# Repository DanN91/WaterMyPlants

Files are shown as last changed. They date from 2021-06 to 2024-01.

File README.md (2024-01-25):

# WaterMyPlants

#### Software and Hardware ( ATMega328P ) system aimed to keep our plants alive for a reasonable amount of time while we enjoy our vacation.

Functionalities ( Strategies, changeable at run-time ):
1. **Manual** mode: turn the water pump on/off via a button push;
2. **Timer** mode: turn the water pump on/off for a specific duration of time and with a specific frequency ( once every x days );
3. **Sensor** mode: monitor the soil moisture and calibrate wetness and dryness levels, then water the plants whenever set dryness level is reached, up to the set wetness level.

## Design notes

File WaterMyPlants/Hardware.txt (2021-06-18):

*** Water My Plants Hardware Components ***

*** Components ***
3 x Momentary Switch
3 x 10k Resistor

1 x 10mm LED
1 x 10k Resistor

1 x Photoresistor
1 x 10k Resistor

1 x 2N2222 Transistor
1 x 1k Resistor

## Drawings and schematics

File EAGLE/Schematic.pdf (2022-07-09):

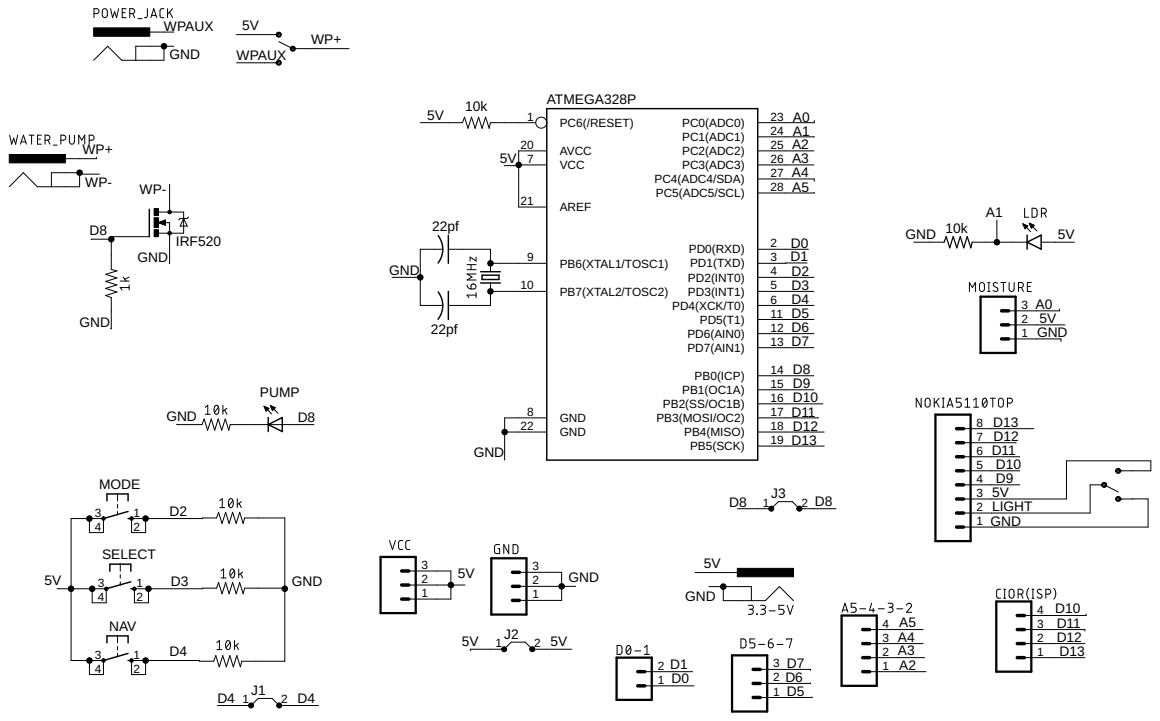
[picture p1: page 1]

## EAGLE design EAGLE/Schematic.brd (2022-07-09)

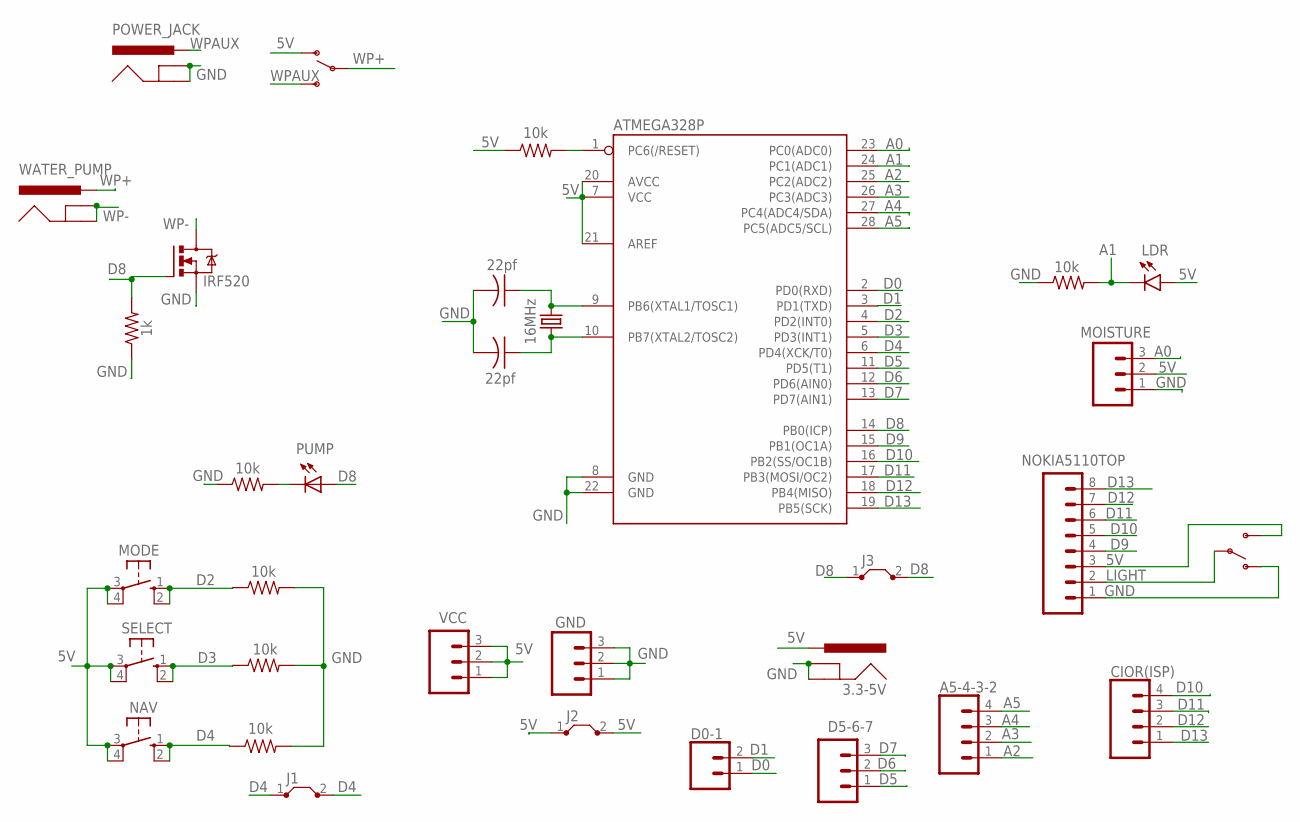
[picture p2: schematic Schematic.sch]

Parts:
3.3-5V: POWER_JACK; POWER_JACK_PTH
5V/AUX: SWITCH-SPDT-PTH-11.6X4.0MM-LOCK; SWITCH_SPDT_PTH_11.6X4.0MM_LOCK
A5-4-3-2: CONN_04; 1X04
ATMEGA328P: 328P; DIP28
AUX_POWER: POWER_JACK; POWER_JACK_PTH
C1, C2: 22pf; C025-024X044
CIOR(ISP): CONN_04; 1X04
D0-1: CONN_02; 1X02
D5-6-7: CONN_03; 1X03
GND: CONN_03; 1X03
GND/VCC: SWITCH-SPDT-PTH-11.6X4.0MM-LOCK; SWITCH_SPDT_PTH_11.6X4.0MM_LOCK
J1, J2, J3: J5MM; 05
LDR: LED3MM; LED_3MM
MODE: 10-XX; B3F-10XX
MOISTURE: CONN_03; 1X03
NAV: 10-XX; B3F-10XX
NOKIA5110TOP: CONN_08"; 1X08
PUMP: LED5MM
Q1: IRF520; TO220BV
R2, R3, R4, R5, R7: 10k; AXIAL-0.1
R6: 10k; 0207/2V
R8: 1k; AXIAL-0.1
SELECT: 10-XX; B3F-10XX
VCC: CONN_03; 1X03
WATER_PUMP: WATER_PUMP; POWER_JACK_PTH
Y1: 16MHz; HC49US

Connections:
5V: 3.3-5V.PWR, 5V/AUX.1 (O), ATMEGA328P.7 (VCC), ATMEGA328P.20 (AVCC), ATMEGA328P.21 (AREF), GND/VCC.3 (S), J2.1, J2.2, LDR.A, MODE.3, MODE.4 (P1), MOISTURE.2, NAV.3, NAV.4 (P1), NOKIA5110TOP.3, R7.P$1 (1), SELECT.3, SELECT.4 (P1), VCC.1, VCC.2, VCC.3
A0: ATMEGA328P.23 (PC0(ADC0)), MOISTURE.3
A1: ATMEGA328P.24 (PC1(ADC1)), LDR.K (C), R6.2
A2: A5-4-3-2.1, ATMEGA328P.25 (PC2(ADC2))
A3: A5-4-3-2.2, ATMEGA328P.26 (PC3(ADC3))
A4: A5-4-3-2.3, ATMEGA328P.27 (PC4(ADC4/SDA))
A5: A5-4-3-2.4, ATMEGA328P.28 (PC5(ADC5/SCL))
D0: ATMEGA328P.2 (PD0(RXD)), D0-1.1
D1: ATMEGA328P.3 (PD1(TXD)), D0-1.2
D2: ATMEGA328P.4 (PD2(INT0)), MODE.1 (S), MODE.2 (S1), R5.P$1 (1)
D3: ATMEGA328P.5 (PD3(INT1)), R4.P$1 (1), SELECT.1 (S), SELECT.2 (S1)
D4: ATMEGA328P.6 (PD4(XCK/T0)), J1.1, J1.2, NAV.1 (S), NAV.2 (S1), R3.P$1 (1)
D5: ATMEGA328P.11 (PD5(T1)), D5-6-7.1
D6: ATMEGA328P.12 (PD6(AIN0)), D5-6-7.2
D7: ATMEGA328P.13 (PD7(AIN1)), D5-6-7.3
D8: ATMEGA328P.14 (PB0(ICP)), J3.1, J3.2, PUMP.A, Q1.G, R8.P$2 (2)
D9: ATMEGA328P.15 (PB1(OC1A)), NOKIA5110TOP.4
D10: ATMEGA328P.16 (PB2(SS/OC1B)), CIOR(ISP).4, NOKIA5110TOP.5
D11: ATMEGA328P.17 (PB3(MOSI/OC2)), CIOR(ISP).3, NOKIA5110TOP.6
D12: ATMEGA328P.18 (PB4(MISO)), CIOR(ISP).2, NOKIA5110TOP.7
D13: ATMEGA328P.19 (PB5(SCK)), CIOR(ISP).1, NOKIA5110TOP.8
GND: 3.3-5V.GND, 3.3-5V.GNDBREAK, ATMEGA328P.8 (GND), ATMEGA328P.22 (GND), AUX_POWER.GND, AUX_POWER.GNDBREAK, C1.2, C2.2, GND.1, GND.2, GND.3, GND/VCC.1 (O), MOISTURE.1, NOKIA5110TOP.1, Q1.S, R2.P$1 (1), R3.P$2 (2), R4.P$2 (2), R5.P$2 (2), R6.1, R8.P$1 (1)
LIGHT: GND/VCC.2, NOKIA5110TOP.2
unnamed: PUMP.K (C), R2.P$2 (2)
unnamed: ATMEGA328P.9 (PB6(XTAL1/TOSC1)), C1.1, Y1.2
unnamed: ATMEGA328P.10 (PB7(XTAL2/TOSC2)), C2.1, Y1.1
unnamed: ATMEGA328P.1 (PC6(/RESET)), R7.P$2 (2)
WP+: 5V/AUX.2, WATER_PUMP.PWR
WP-: Q1.D, WATER_PUMP.GND, WATER_PUMP.GNDBREAK
WPAUX: 5V/AUX.3 (S), AUX_POWER.PWR

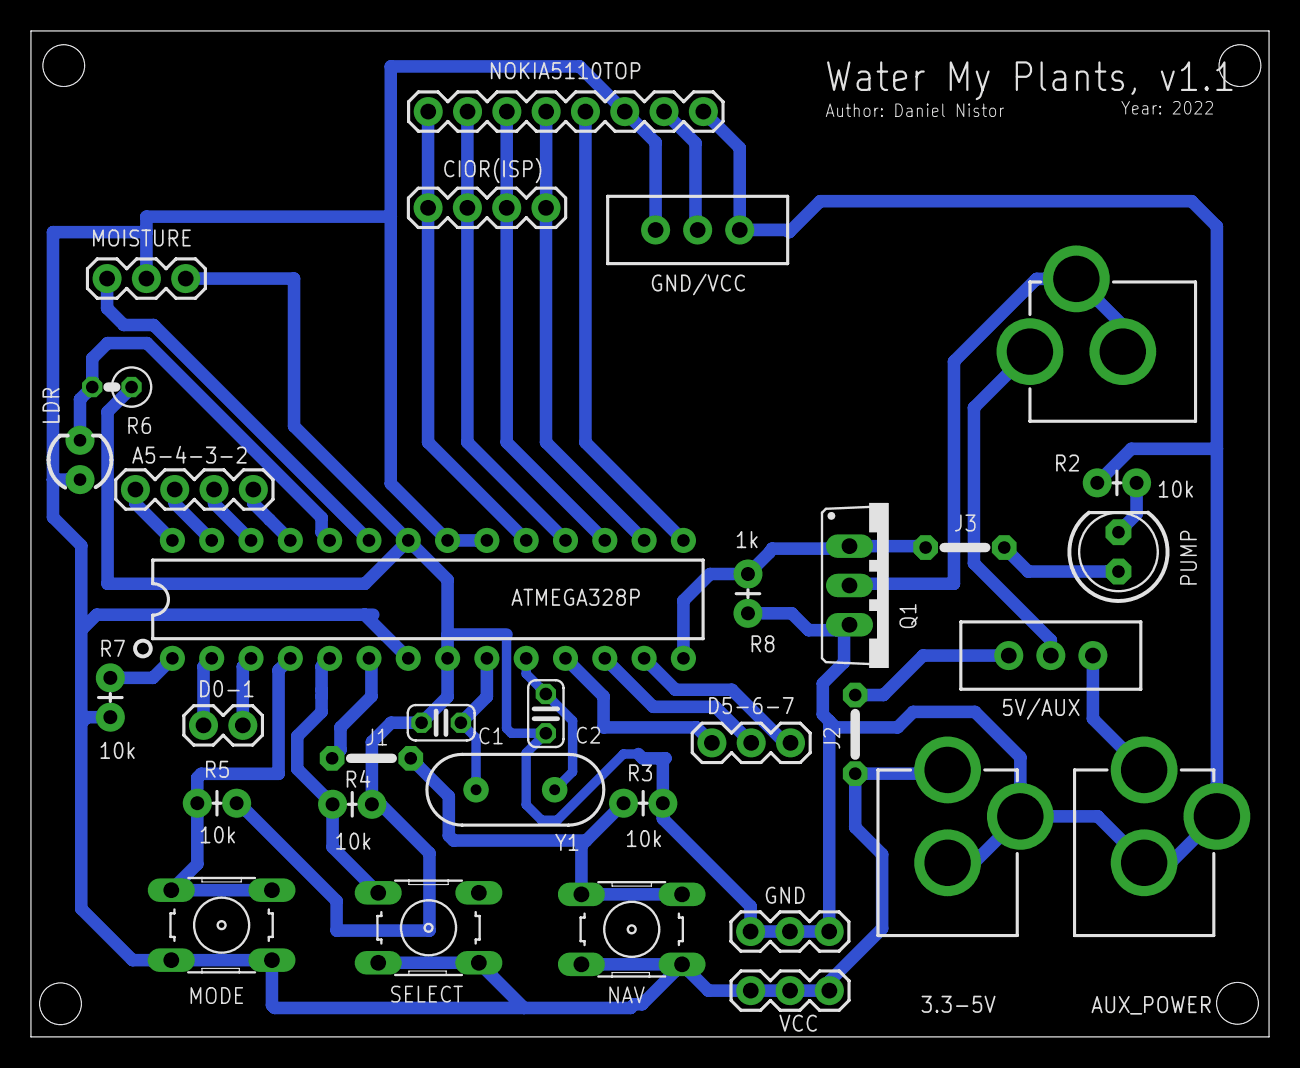
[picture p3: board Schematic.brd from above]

Board: 2 copper layers, 80.0 x 65.0 mm, 33 parts (0 on the bottom side), 30 nets.

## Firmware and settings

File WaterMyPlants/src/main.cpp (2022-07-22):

#include <Arduino.h>

#include <Hardware.h>
#include <PushButton.h>
#include <NokiaDisplay.h>
#include <MenuCursor.h>
#include <MenuCreator.h>
#include <MenuController.h>
#include <SettingsManager.h>
#include <StringsManager.h>
#include <TimerManager.h>

#include <SoilMoistureSensor.h>
#include <LightSensor.h>

#include <OperationModeHandler.h>
#include <RangeValuesGenerator.h>
#include <ChangeSetting.h>

#include <ManualMode.h>
#include <TimerMode.h>
#include <SensorMode.h>

#include <Menu.h>

PushButton modeChangerButton(Hardware::MODE_CHANGER_BUTTON_PIN);
PushButton executionButton(Hardware::EXECUTION_BUTTON_PIN);
OperationModeHandler operationHandler(modeChangerButton);

NokiaDisplay display(Hardware::NOKIA_RESET_PIN,
    Hardware::NOKIA_CHIP_ENABLE_PIN,
    Hardware::NOKIA_DATA_SELECT_PIN,
    Hardware::NOKIA_DATA_IN_PIN,
    Hardware::NOKIA_CLOCK_PIN);
PushButton menuNavigationButton(Hardware::MENU_NAVIGATION_BUTTON_PIN);
MenuController menuController(display, modeChangerButton, menuNavigationButton, executionButton, operationHandler);

// Operation Modes
WaterPump waterPump(Hardware::WATER_PUMP_PIN);
ManualMode manualMode(waterPump, executionButton);

TimerManager timerManager(1); // Observers: [TimerMode]
TimerMode timerMode(waterPump, timerManager);

SoilMoistureSensor soilMoistureSensor(Hardware::SOIL_MOISTURE_SENSOR_PIN, SoilMoistureSensor::Sensitivity::Medium);
LightSensor lightSensor(Hardware::LIGHT_SENSOR_PIN, LightSensor::Sensitivity::High);
SensorMode sensorMode(soilMoistureSensor, lightSensor, waterPump);

void setup()
{
    // Serial.begin(115200); // #TODO:TESTONLY
    timerManager.Initialize();
    timerManager.Activate();

    // Operation Mode Handler
    operationHandler.Add(manualMode);
    operationHandler.Add(timerMode);
    operationHandler.Add(sensorMode);

    operationHandler.Initialize();

    // initialize hardware components
    modeChangerButton.Initialize();
    menuNavigationButton.Initialize();
    executionButton.Initialize();
    waterPump.Initialize();

    // call once, then comment and recompile + upload
    // StringsManager stringsManager(Language::English);
    // stringsManager.WriteAllStrings();
    // SettingsManager::WriteDefaultSettings();

    display.Initialize();
    menuController.Initialize();
}

uint32_t previous = millis();

// CALIBRATION ONLY
uint16_t minMoisture = 1000;
uint16_t maxMoisture = 0;

uint16_t minLight = 1000;
uint16_t maxLight = 0;

void loop()
{
    // buttons
    modeChangerButton.HandleEvents();
    menuNavigationButton.HandleEvents();
    executionButton.HandleEvents();
    lightSensor.HandleEvents();
    soilMoistureSensor.HandleEvents();

    operationHandler.Run();
    menuController.Handle();

    // on Manual menu show this data for calibration purposes
    if (menuController.IsEmptyMenu() && (millis() - previous) >= 1500) // once every second
    {
        // const auto PrintSensorValues = [](const char* name, uint16_t rawValue, uint8_t percentValue){
        //     Serial.print(name);
        //     Serial.print(rawValue);
        //     Serial.print(" ( ");
        //     Serial.print(percentValue);
        //     Serial.println(" % )");
        // };

        const auto lightValue = lightSensor.RawValue();
        // const auto lightPercent = lightSensor.Value();
        // PrintSensorValues("Light: ", lightValue, lightPercent);

        const auto moistureValue = soilMoistureSensor.RawValue();
        // const auto moisturePercent = soilMoistureSensor.Value();
        // PrintSensorValues("Moisture: ", moistureValue, moisturePercent);

        display.SetCursor(4, 0);
        display.ClearLine();

        String currentLight("L: ");
        currentLight.concat(lightValue);
        currentLight.concat("/");
        currentLight.concat(lightSensor.Value());
        currentLight.concat(" %");

        display.Write(currentLight);

        display.SetCursor(5, 0);
        display.ClearLine();

        String currentMoisture("M: ");
        currentMoisture.concat(moistureValue);
        currentMoisture.concat("/");
        currentMoisture.concat(soilMoistureSensor.Value());
        currentMoisture.concat(" %");

        display.Write(currentMoisture);

        // Update and show Min and Max
        if (moistureValue < minMoisture)
            minMoisture = moistureValue;

        if (moistureValue > maxMoisture)
            maxMoisture = moistureValue;

        if (lightValue < minLight)
            minLight = lightValue;

        if (lightValue > maxLight)
            maxLight = lightValue;

        String lightStats("L: ");
        lightStats.concat(minLight);
        lightStats.concat("/");
        lightStats.concat(maxLight);

        display.SetCursor(2, 0);
        display.ClearLine();
        display.Write(lightStats);

        String moistureStats("M: ");
        moistureStats.concat(minMoisture);
        moistureStats.concat("/");
        moistureStats.concat(maxMoisture);

        display.SetCursor(3, 0);
        display.ClearLine();
        display.Write(moistureStats);

        previous = millis();
    }
}

// ISR used by timer manager to notify observers
ISR(TIMER1_COMPA_vect)
{
    timerManager.OnTrigger();
}

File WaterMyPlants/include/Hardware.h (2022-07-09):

/*
    ...
*/

#pragma once

#include <Arduino.h>

namespace Hardware
{
    constexpr uint8_t SOIL_MOISTURE_SENSOR_PIN = A0;
    constexpr uint8_t LIGHT_SENSOR_PIN = A1;

    constexpr uint8_t WATER_PUMP_PIN = 8;
    constexpr uint8_t MODE_CHANGER_BUTTON_PIN = 2;
    constexpr uint8_t EXECUTION_BUTTON_PIN = 3;
    constexpr uint8_t MENU_NAVIGATION_BUTTON_PIN = 4;

    constexpr uint8_t NOKIA_RESET_PIN = 13;
    constexpr uint8_t NOKIA_CHIP_ENABLE_PIN = 12;
    constexpr uint8_t NOKIA_DATA_SELECT_PIN = 11;
    constexpr uint8_t NOKIA_DATA_IN_PIN = 10;
    constexpr uint8_t NOKIA_CLOCK_PIN = 9;
}

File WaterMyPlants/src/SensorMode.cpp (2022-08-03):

/*
    SensorMode: Waters the plants by night autonomously using a light and a soil moisture sensor.
    Author: Daniel Nistor
    MIT License, 2021
*/
#include "SensorMode.h"

#include <SettingsManager.h>
#include <Constants.h>

namespace
{
    constexpr uint8_t WATERING_DURATION_SEC = 30;
    constexpr uint8_t WAITING_BREAK_MIN = 1;
} // anonymous

SensorMode::SensorMode(SoilMoistureSensor& soilMoistureSensor, LightSensor& lightSensor, WaterPump& waterPump)
    : IObserver<SoilMoistureEvent>(SoilMoistureEvent::MoistureChanged, soilMoistureSensor)
    , IObserver<LightSensorEvent>(LightSensorEvent::IntensityChanged, lightSensor)
    , m_soilMoistureSensor(soilMoistureSensor)
    , m_lightSensor(lightSensor)
    , m_waterPump(waterPump)
{
}

SensorMode::~SensorMode()
{
    StopWatering();
}

void SensorMode::OnEvent(LightSensorEvent event)
{
    // const auto lightPercent = m_lightSensor.Value();

    // Serial.print("Light: ");
    // Serial.println(lightPercent);

    HandleSensorsChanges();
}

void SensorMode::OnEvent(SoilMoistureEvent event)
{
    // const auto moisturePercent = m_soilMoistureSensor.Value();

    // Serial.print("Moisture: ");
    // Serial.println(moisturePercent);

    HandleSensorsChanges();
}

void SensorMode::Run()
{
    if (IsNight() && IsSoilDry())
    {
        if (IsTimeToTakeABrake()) // give some time for water to be absorbed
        {
            StopWatering();
            m_isBreakNow = true;
        }
        else if (!m_isBreakNow)
        {
            StartWatering();
        }
    }
}

void SensorMode::Activate()
{
    IObserver<SoilMoistureEvent>::Register();
    IObserver<LightSensorEvent>::Register();
}

void SensorMode::Deactivate()
{
    StopWatering();
    m_isBreakNow = false; // cancel break

    IObserver<SoilMoistureEvent>::Unregister();
    IObserver<LightSensorEvent>::Unregister();
}

void SensorMode::StartWatering()
{
    if (!m_isBreakNow && !m_waterPump.IsOn())
    {
        m_waterPump.TurnOn();
        m_startedAtMs = millis();
    }
}

void SensorMode::StopWatering()
{
    if (m_waterPump.IsOn())
    {
        m_waterPump.TurnOff();
        m_stoppedAtMs = millis();
    }
}

inline bool SensorMode::IsSoilDry() const
{
    // if watering has started, we need to water until the Wet threshold is reached
    return m_waterPump.IsOn() ? !IsSoilWet() : (m_soilMoistureSensor.Value() <= SettingsManager::Read(Settings::Address::SensorModeDry));
}

inline bool SensorMode::IsSoilWet() const
{
    return m_soilMoistureSensor.Value() >= SettingsManager::Read(Settings::Address::SensorModeWet);
}

inline bool SensorMode::IsNight() const
{
    return m_lightSensor.Value() <= SettingsManager::Read(Settings::Address::SensorModeLightThreshold);
}

bool SensorMode::IsTimeToTakeABrake() const
{
    // true: if watering has run for WATERING_DURATION_SEC and the soil is still not WET
    // take a break and let the soil absorb the water
    // false: if WAITING_BREAK_MIN elapsed and the soil is still DRY
    // restart watering for WATERING_DURATION_SEC
    if (m_waterPump.IsOn() && (millis() - m_startedAtMs) >= (WATERING_DURATION_SEC * Constants::Time::SECOND_MS)) // watering cycle
    {
        return IsSoilDry();
    }
    else if (m_isBreakNow && (millis() - m_stoppedAtMs) >= (WAITING_BREAK_MIN * Constants::Time::MINUTE_MS)) // break is over
    {
        m_isBreakNow = false;
        return IsSoilWet();
    }

    return false;
}

void SensorMode::HandleSensorsChanges()
{
    (IsNight() && IsSoilDry()) ? StartWatering() : StopWatering();

    if (m_isBreakNow && IsSoilWet()) // cancel break
        m_isBreakNow = false;
}

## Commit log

2021-06-18 WaterMyPlants : Implemented 3 operation modes
    Changelog
    Added PlatformIO project
    WaterPump : Wrapper over water pump hardware
    Some Cleanup
    Renamed Automatic to TimerMode
    WaterPump: make it non-copyable and non-movable
    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
2022-06-06 TimerMode: fix time bug and make conditions easier to understand
2022-06-09 EAGLE: Added schematics and board design, todo export gerber
    [Schematic.brd, Schematic.sch]
2022-07-09 EAGLE: added gerber files
    [Schematic.brd, Schematic.sch]
2022-07-09 Fuses: added .bat for setting the fuses to fit the project's needs
2022-07-09 PlatformIO: add configuration for Uploading by Arduino as ISP
2022-07-22 TimerMode: use TimerManager for tracking the time
2022-08-03 SensorMode: adapt to real world scenarios
2022-08-04 TimerMode: use TimerEvent for starting and stopping the watering

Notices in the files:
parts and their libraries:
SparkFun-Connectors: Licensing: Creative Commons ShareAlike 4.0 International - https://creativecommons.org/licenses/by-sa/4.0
